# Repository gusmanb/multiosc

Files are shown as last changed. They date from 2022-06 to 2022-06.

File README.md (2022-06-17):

# MultiOsc
----
## Description
Two-channel 7Khz to 200Mhz clock/oscillator.

----
## Overview
MultiOsc is a very cheap two-channel clock generator which can be configured to generate frequencies from 8Khz to 200Mhz (180 to 200, depends on the SI5153 version) for less than 10€.

The device is based on the SI5351 clock generator, more concretely using the module sold in AliExpress (for less than 4€) which is very convenient as it already contains all the required external components to get it working immediately.

The device uses a STM32F103 module to control the clock generator and drive a 0.66" I2C screen.

## Schematic

The schematic is extremely simple, the three modules are connected through the I2C bus and five push buttons are used to control de menus, nothing more nothing else :)

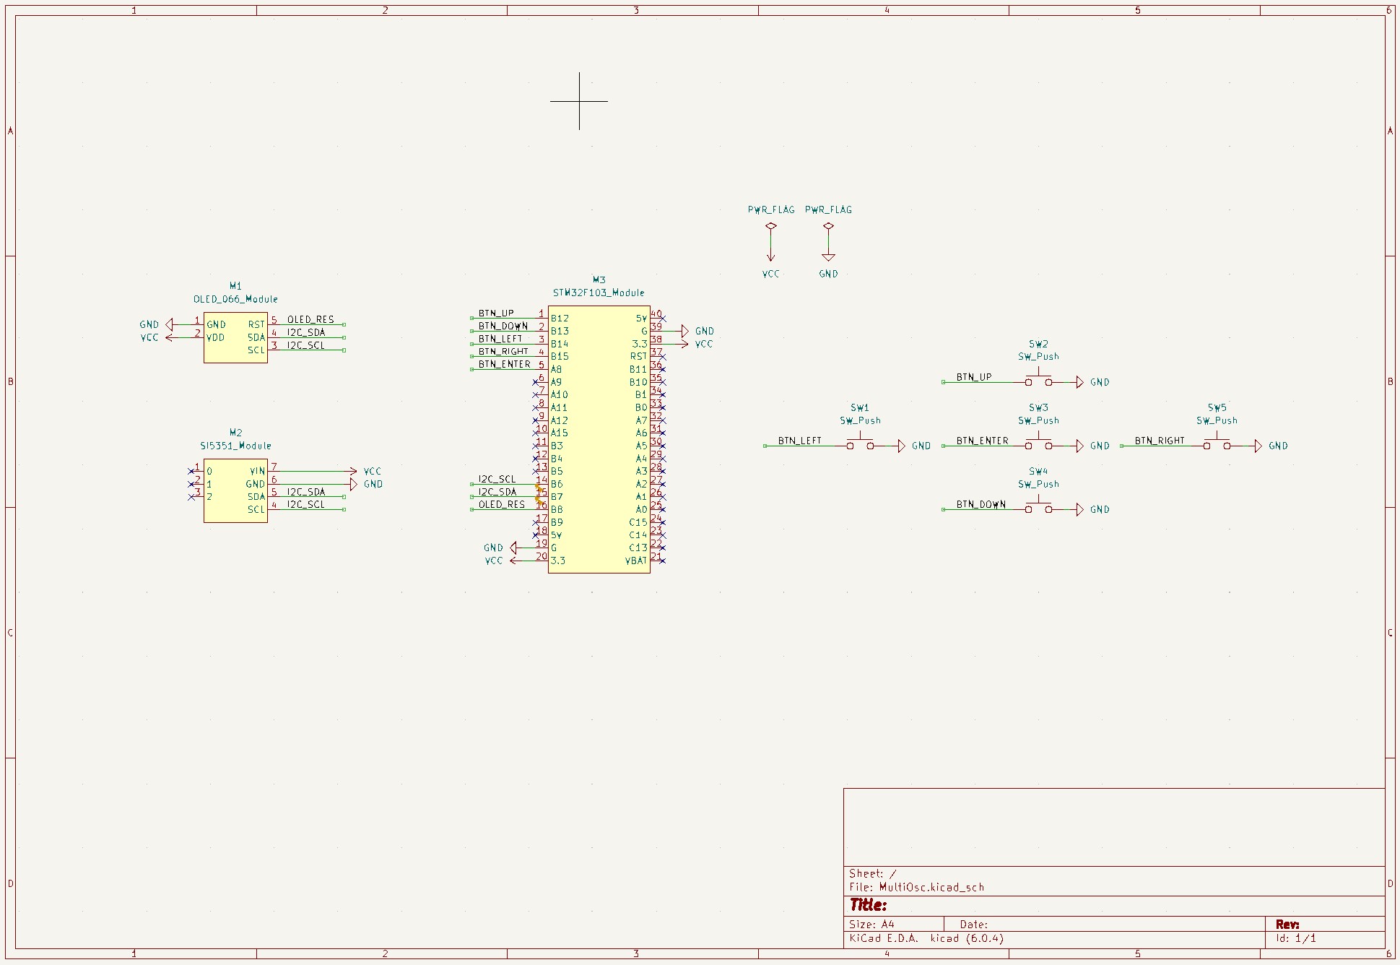
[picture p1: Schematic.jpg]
Schematic picture Schematic


## PCB

I also have included a very basic PCB to construct the device but it's not needed at all. I have assembled it using a protoboard and it works really well, but for anyone who wants to make it more robust the PCB is a good option.

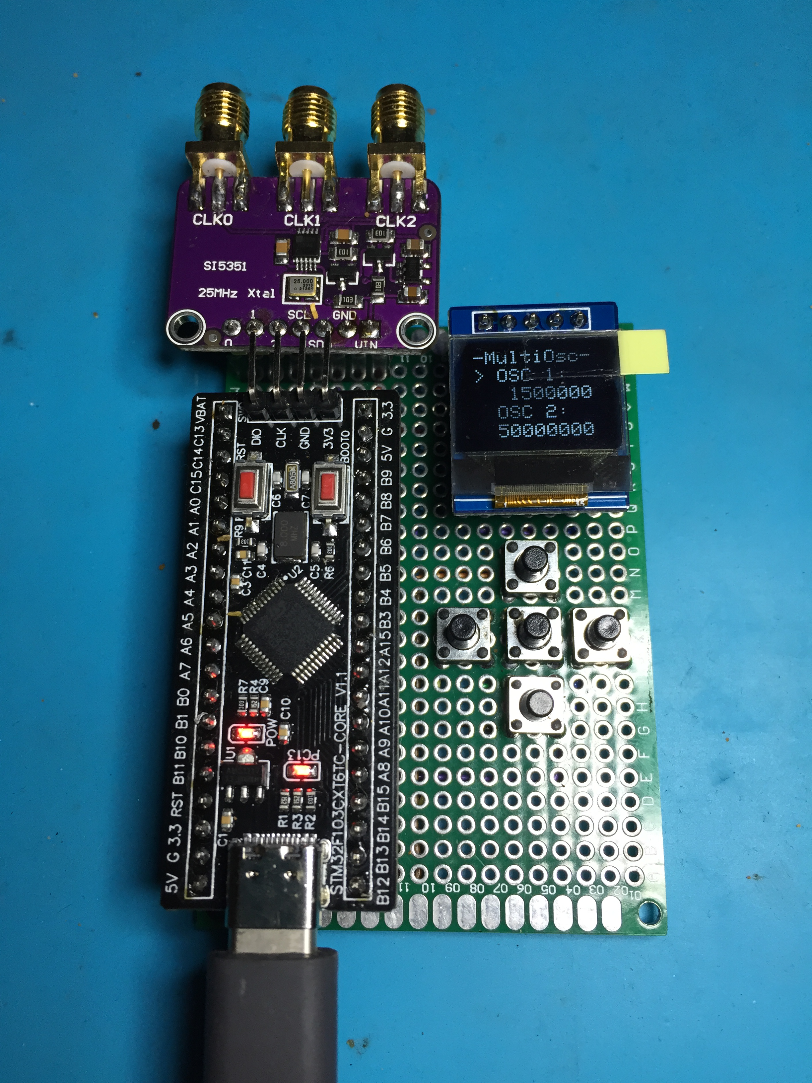
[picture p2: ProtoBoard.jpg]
ProtoBoard picture 1 ProtoBoard 1


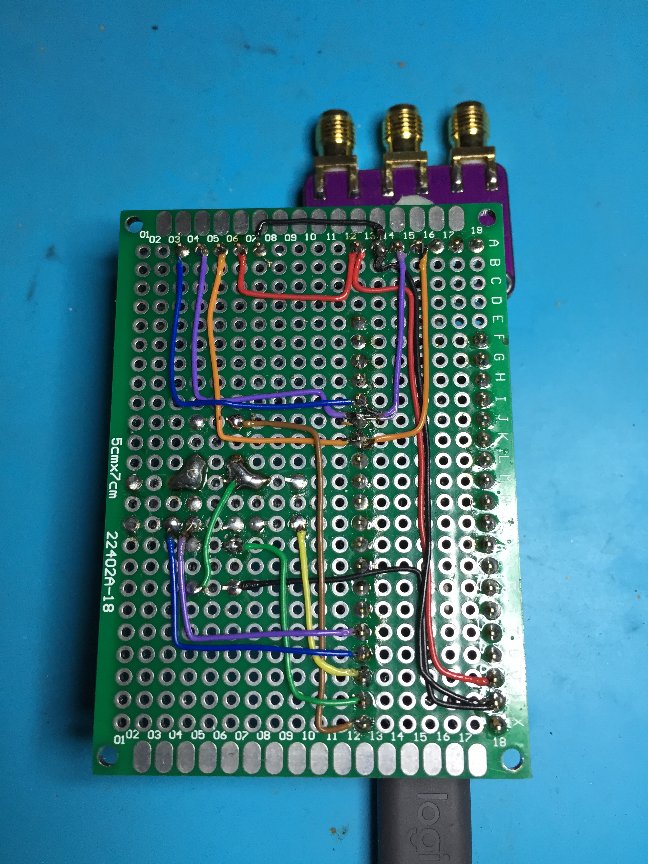
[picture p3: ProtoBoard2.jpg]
ProtoBoard picture 2 ProtoBoard 2


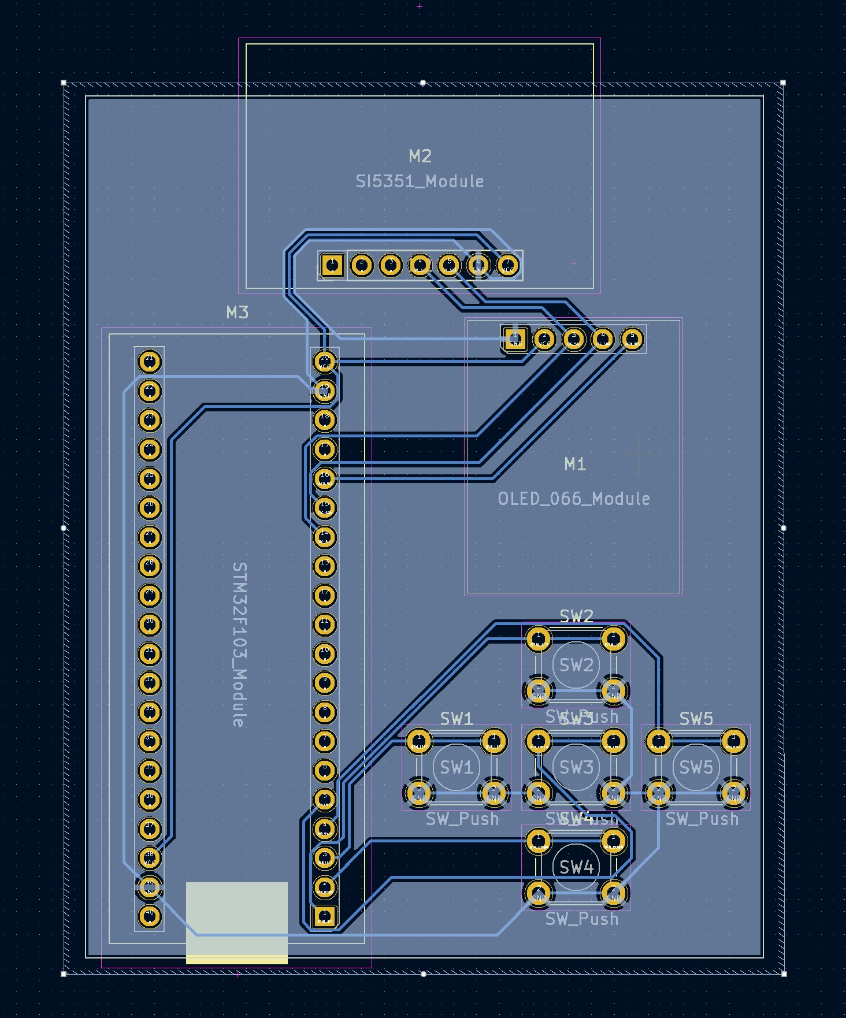
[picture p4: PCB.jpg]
PCB picture PCB


Both, schematic and PCB are included under the "PCB" folder, it's a KiCad 6.0 project and it includes all the custom footprints for the modules in case you want to reuse them.

## BOM

The bill of materials is very reduced:

* STM32F103 module:  https://es.aliexpress.com/item/1005002441720435.html
* 0.66" OLED screen: https://es.aliexpress.com/item/1005002760899272.html
* SI5351 module:     https://es.aliexpress.com/item/32915414654.html
* Push buttons (5):  https://es.aliexpress.com/item/1005004001434474.html

I am 99.99999% sure the STM module uses a clone uC, not an original STM device, but as far as I can tell the device works flawlessly.

## STM32F103 bootloader

I have seen a lot of people complaining about the F103 modules failing to run the bootloader, but this is all a missunderstanding on how the bootloader works for the F103.

If you check carefully the [AN2606](https://www.st.com/resource/en/application_note/cd00167594-stm32-microcontroller-system-memory-boot-mode-stmicroelectronics.pdf) it clarifies the problem and is really simple, the STM32F10XXX family only has UART bootloader and the modules connect the USB connector to the USB pins from these devices, there is no integrated serial-to-usb converter so the bootloader will not work connecting only the USB port, you also need a serial-to-usb converter and connect it to pins PA9 and PA10, with this the device will be accessible from STM32CubeProgrammer.

In any case I recommend to use a ST-LINK/V2 or similar (I have an original one and a clone, both work but the original one is less prone to cause errors and can be upgraded, so if you can, buy an original one), it works a lot faster and allows to debug the code in real time.

## Firmware

The firmware project is a STM32CubeIde project, currently I have used the 1.9.0 version and it uses the standard drivers and two heavily modified libraries.

The first library is the SSD1306 library by afiskon and you can find the original here: https://github.com/afiskon/stm32-ssd1306
The second library is the SI5351 library by MR-DOS and you can find the original here: https://github.com/MR-DOS/Si5351-lib

As you can imagine the firmware itself is very simple, it creates a menu where you can change the two output frequencies and that's all, nothing else is needed, and as it relies on the two aforementioned libraries controlling the screen and the SI module is a breeze.

Beware that I found there is a problem with CubeMX, if you open the CubeMX file to reconfigure the HAL drivers, pinout or whatever the CubeMX does break the I2C configuration, for the F103 device it does not allow to configure the port speed and without the configuration the I2C bus does not work. If you need to reconfigure the hardware, after re-generating the files you will need to modify the file "stm32f1xx_hal_msp.c" and add to the I2C initialization, before the "HAL_GPIO_Init" call, this: 

	GPIO_InitStruct.Speed = GPIO_SPEED_FREQ_HIGH;

---

Have fun!

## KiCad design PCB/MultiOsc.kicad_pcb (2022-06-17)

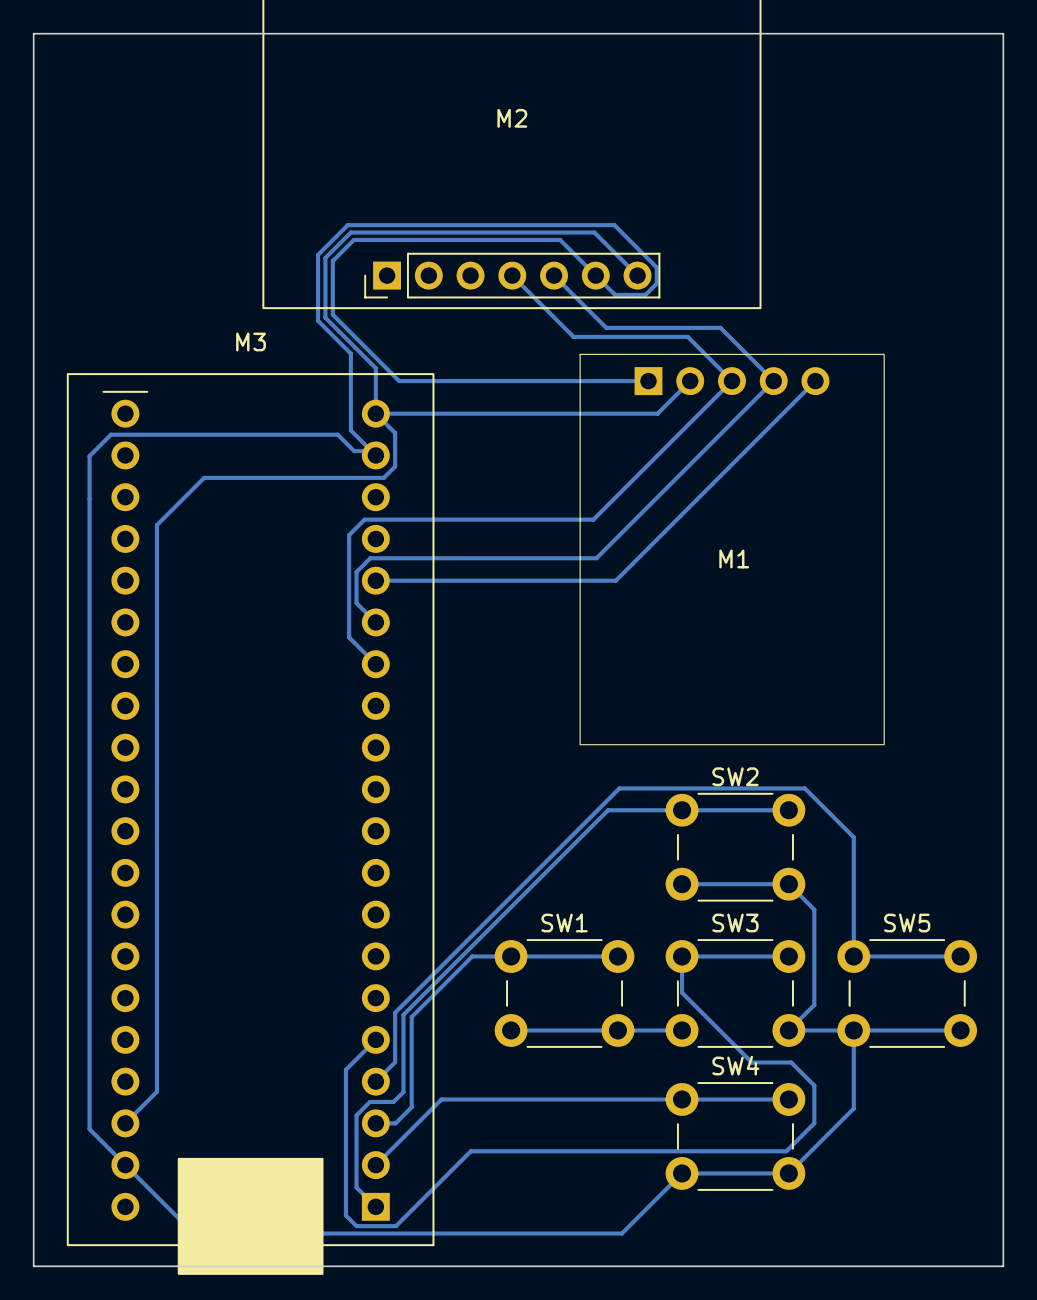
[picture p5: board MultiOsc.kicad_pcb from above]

Board: 2 copper layers, 59.0 x 75.0 mm, 8 parts (0 on the bottom side), 10 nets.

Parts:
M1: OLED_066_Module
M2: SI5351_Module
M3: STM32F103_Module
SW1, SW2, SW3, SW4, SW5: SW_Push; SW_PUSH_6mm_H7.3mm

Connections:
/BTN_DOWN: M3.2 (B13), SW4.1
/BTN_ENTER: M3.5 (A8), SW3.1
/BTN_LEFT: M3.3 (B14), SW1.1
/BTN_RIGHT: M3.4 (B15), SW5.1
/BTN_UP: M3.1 (B12), SW2.1
/I2C_SCL: M1.3 (SCL), M2.4 (SCL), M3.14 (B6)
/I2C_SDA: M1.4 (SDA), M2.5 (SDA), M3.15 (B7)
/OLED_RES: M1.5 (RST), M3.16 (B8)
GND: M1.1 (GND), M2.6 (GND), M3.19 (G), M3.39 (G), SW1.2, SW2.2, SW3.2, SW4.2, SW5.2
VCC: M1.2 (VDD), M2.7 (VIN), M3.20 (3.3), M3.38 (3.3)

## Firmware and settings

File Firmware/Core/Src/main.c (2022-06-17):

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
/* Includes ------------------------------------------------------------------*/
#include "main.h"

/* USER CODE BEGIN Includes */
#include "string.h"
#include "stdio.h"
#include "stdlib.h"
/* USER CODE END Includes */

/* USER CODE BEGIN PD */
#define XTAL_FREQ 25000000
/* USER CODE END PD */

 I2C_HandleTypeDef hi2c1;

/* USER CODE BEGIN PV */

Si5351_ConfigTypeDef si1;
uint32_t channel0Freq;
uint32_t channel1Freq;
uint8_t selectedChannel;
uint8_t currentChar;
uint8_t currentMenu;

char textBuffer[16];
char editBuffer[16];

/* USER CODE END PV */

void SystemClock_Config(void);
static void MX_GPIO_Init(void);
static void MX_I2C1_Init(void);
/* USER CODE BEGIN PFP */
static void MX_SI_Init(void);
static void MX_SCR_Init(void);
/* USER CODE END PFP */

/* USER CODE BEGIN 0 */

void SetFrequency(uint8_t channel, uint32_t desiredFrequency)
{

	uint32_t pllFreq;
	uint32_t l;
	float f;
	uint8_t mult;
	uint32_t num;
	uint32_t denom;
	uint32_t divider;
	Si5351_CLKRDivTypeDef rDivider = CLK_R_Div1;

	if(desiredFrequency == 0)
	{
		si1.CLK[channel].CLK_Enable = OFF;
		Si5351_Init(&si1);
		if(channel == 0)
			channel0Freq = 0;
		else
			channel1Freq = 0;

		return;
	}

	if(desiredFrequency < 1000000)
	{
		rDivider = CLK_R_Div64;
		divider = 900000000 / (desiredFrequency * 64);

		if (divider % 2)
			divider--;

		pllFreq = divider * desiredFrequency * 64;
	}
	else
	{
		divider = 900000000 / desiredFrequency;

		if (divider % 2)
			divider--;

		pllFreq = divider * desiredFrequency;
	}

	mult = pllFreq / XTAL_FREQ;
	l = pllFreq % XTAL_FREQ;

	if(l == 0)
	{
		num = 0;
		denom = 1;
	}
	else
	{
		f = l;


		f /= XTAL_FREQ;
		f *= 1048575;
		num = f;
		denom = 1048575;
	}

	float finalFreq = (25000000 * (float)(mult + (float)num / (float)denom)) / (divider);

	if(rDivider != CLK_R_Div1)
		finalFreq /= 64;

	si1.PLL[channel].PLL_Multiplier_Integer = mult; //800Mhz
	si1.PLL[channel].PLL_Multiplier_Numerator = num;
	si1.PLL[channel].PLL_Multiplier_Denominator = denom;
	si1.MS[channel].MS_Divider_Integer = divider;
	si1.CLK[channel].CLK_R_Div = rDivider;
	si1.CLK[channel].CLK_Enable = ON;

	Si5351_Init(&si1);
	Si5351_PLLReset(&si1, channel);

	if(channel == 0)
		channel0Freq = finalFreq;
	else
		channel1Freq = finalFreq;
}

void SelectOsc(uint8_t oscChannel)
{

	selectedChannel = oscChannel;
	if(oscChannel == 0)
	{
		ssd1306_SetCursor(0, 10);
		ssd1306_WriteString(">", Font_6x8, White);
		ssd1306_SetCursor(0, 30);
		ssd1306_WriteString(" ", Font_6x8, White);
	}
	else
	{
		ssd1306_SetCursor(0, 10);
		ssd1306_WriteString(" ", Font_6x8, White);
		ssd1306_SetCursor(0, 30);
		ssd1306_WriteString(">", Font_6x8, White);
	}

	ssd1306_UpdateScreen();
}

void ShowCurrentOscConfig()
{
	size_t freqLen;

	ssd1306_Fill(Black);

	ssd1306_SetCursor(0, 0);
	ssd1306_WriteString("-MultiOsc-", Font_6x8, White);

	ssd1306_SetCursor(0, 10);
	ssd1306_WriteString("  OSC 1:", Font_6x8, White);

	memset(textBuffer, 0, 16);
	sprintf(textBuffer, "%lu", channel0Freq);
	freqLen = strlen(textBuffer);

	ssd1306_SetCursor((10 - freqLen) * 6, 20);
	ssd1306_WriteString(textBuffer, Font_6x8, White);

	ssd1306_SetCursor(0, 30);
	ssd1306_WriteString("  OSC 2:", Font_6x8, White);

	memset(textBuffer, 0, 16);
	sprintf(textBuffer, "%lu", channel1Freq);
	freqLen = strlen(textBuffer);

	ssd1306_SetCursor((10 - freqLen) * 6, 40);
	ssd1306_WriteString(textBuffer, Font_6x8, White);

	SelectOsc(0);
}

uint8_t DebounceButton(GPIO_TypeDef* Port, uint16_t Pin)
{
	if(!HAL_GPIO_ReadPin(Port, Pin))
	{
		while(!HAL_GPIO_ReadPin(Port, Pin))
			HAL_Delay(1);

		HAL_Delay(50);

		return 1;
	}

	return 0;
}

void IncrementChar()
{
	uint8_t charIndex = 8 - currentChar;

	editBuffer[charIndex]++;

	if(editBuffer[charIndex] > 57)
		editBuffer[charIndex] = 48;

	ssd1306_SetCursor(6, 16);
	ssd1306_WriteString(editBuffer, Font_6x8, White);

	ssd1306_UpdateScreen();
}

void DecrementChar()
{
	uint8_t charIndex = 8 - currentChar;

	editBuffer[charIndex]--;

	if(editBuffer[charIndex] < 48)
		editBuffer[charIndex] = 57;

	ssd1306_SetCursor(6, 16);
	ssd1306_WriteString(editBuffer, Font_6x8, White);

	ssd1306_UpdateScreen();
}

void SelectChar(uint8_t charNumber)
{
	currentChar = charNumber;

	memset(textBuffer, ' ', 10);
	textBuffer[10] = 0;
	textBuffer[9 - charNumber] = '^';

	ssd1306_SetCursor(0, 24);
	ssd1306_WriteString(textBuffer, Font_6x8, White);

	ssd1306_UpdateScreen();
}

void ShowEditOscConfig()
{

	size_t freqLen;
	uint32_t currentFreq = selectedChannel? channel1Freq : channel0Freq;

	if(currentFreq == 0)
	{
		memset(editBuffer, 48, 10);
		editBuffer[9] = 0;
	}
	else
	{
		sprintf(editBuffer, "%lu", currentFreq);
		freqLen = strlen(editBuffer);
		memset(editBuffer, 48, 9);
		sprintf(&editBuffer[9 - freqLen], "%lu", currentFreq);
	}

	ssd1306_Fill(Black);
	ssd1306_SetCursor(0, 0);

	if(selectedChannel == 0)
		ssd1306_WriteString("SET OSC 1:", Font_6x8, White);
	else
		ssd1306_WriteString("SET OSC 2:", Font_6x8, White);

	ssd1306_SetCursor(6, 16);
	ssd1306_WriteString(editBuffer, Font_6x8, White);

	SelectChar(0);
}

/* USER CODE END 0 */

/**
  * @brief  The application entry point.
  * @retval int
  */
int main(void)
{
  /* MCU Configuration--------------------------------------------------------*/

  /* Reset of all peripherals, Initializes the Flash interface and the Systick. */
  HAL_Init();

  /* Configure the system clock */
  SystemClock_Config();

  /* Initialize all configured peripherals */
  MX_GPIO_Init();
  MX_I2C1_Init();
  /* USER CODE BEGIN 2 */

  MX_SI_Init();
  MX_SCR_Init();
  /* USER CODE END 2 */

  /* Infinite loop */
  /* USER CODE BEGIN WHILE */
  while (1)
  {
    /* USER CODE END WHILE */

    /* USER CODE BEGIN 3 */

	  HAL_GPIO_TogglePin(LED_GPIO_Port, LED_Pin);


	  if(currentMenu == 0)
	  {
		  if(DebounceButton(BTN_UP_GPIO_Port, BTN_UP_Pin) || DebounceButton(BTN_DOWN_GPIO_Port, BTN_DOWN_Pin))
		  {
			  if(selectedChannel == 0)
				  SelectOsc(1);
			  else
				  SelectOsc(0);
		  }
		  else if(DebounceButton(BTN_ENTER_GPIO_Port, BTN_ENTER_Pin))
		  {
			  currentMenu = 1;
			  ShowEditOscConfig();
		  }
	  }
	  else
	  {
		  if(DebounceButton(BTN_LEFT_GPIO_Port, BTN_LEFT_Pin))
		  {
			  currentChar++;
			  if(currentChar > 8)
				  currentChar = 0;

			  SelectChar(currentChar);
		  }
		  else if(DebounceButton(BTN_RIGHT_GPIO_Port, BTN_RIGHT_Pin))
		  {
			  currentChar--;
			  if(currentChar > 8)
				  currentChar = 8;

			  SelectChar(currentChar);
		  }
		  else if(DebounceButton(BTN_UP_GPIO_Port, BTN_UP_Pin))
		  {
			  IncrementChar();
		  }
		  else if (DebounceButton(BTN_DOWN_GPIO_Port, BTN_DOWN_Pin))
		  {
			  DecrementChar();
		  }
		  else if(DebounceButton(BTN_ENTER_GPIO_Port, BTN_ENTER_Pin))
		  {
			  uint32_t newFreq = (unsigned)atol(editBuffer);

			  if(newFreq < 7000)
				  newFreq = 0;

			  SetFrequency(selectedChannel, newFreq);
			  currentMenu = 0;
			  ShowCurrentOscConfig();
		  }
	  }

  }
  /* USER CODE END 3 */
}

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
/* USER CODE BEGIN 4 */

static void MX_SI_Init(void)
{
	Si5351_StructInit(&si1, &hi2c1);
	si1.OSC.OSC_XTAL_Load = XTAL_Load_10_pF;

	si1.PLL[0].PLL_Clock_Source = PLL_Clock_Source_XTAL;
	si1.PLL[0].PLL_Multiplier_Integer = 32; //800Mhz
	si1.MS[0].MS_Clock_Source = MS_Clock_Source_PLLA;
	si1.MS[0].MS_Divider_Integer = 80; //10Mhz
	si1.CLK[0].CLK_R_Div = CLK_R_Div1;
	si1.CLK[0].CLK_Enable = OFF;

	si1.PLL[1].PLL_Clock_Source = PLL_Clock_Source_XTAL;
	si1.PLL[1].PLL_Multiplier_Integer = 32; //800Mhz
	si1.MS[1].MS_Clock_Source = MS_Clock_Source_PLLB;
	si1.MS[1].MS_Divider_Integer = 50; //10Mhz
	si1.CLK[1].CLK_R_Div = CLK_R_Div16; //1Mhz
	si1.CLK[1].CLK_Enable = OFF;

	si1.CLK[2].CLK_Enable = OFF;

	Si5351_Init(&si1);

	channel0Freq = 0;
	channel1Freq = 0;
}

static void MX_SCR_Init(void)
{
	ssd1306_Init();
	ShowCurrentOscConfig();
}

/* USER CODE END 4 */
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


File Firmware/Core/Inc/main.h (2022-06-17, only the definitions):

#define LED_Pin GPIO_PIN_13
#define LED_GPIO_Port GPIOC
#define BTN_UP_Pin GPIO_PIN_12
#define BTN_UP_GPIO_Port GPIOB
#define BTN_DOWN_Pin GPIO_PIN_13
#define BTN_DOWN_GPIO_Port GPIOB
#define BTN_LEFT_Pin GPIO_PIN_14
#define BTN_LEFT_GPIO_Port GPIOB
#define BTN_RIGHT_Pin GPIO_PIN_15
#define BTN_RIGHT_GPIO_Port GPIOB
#define BTN_ENTER_Pin GPIO_PIN_8
#define BTN_ENTER_GPIO_Port GPIOA
#define OLED_RESET_PIN_Pin GPIO_PIN_8
#define OLED_RESET_PIN_GPIO_Port GPIOB

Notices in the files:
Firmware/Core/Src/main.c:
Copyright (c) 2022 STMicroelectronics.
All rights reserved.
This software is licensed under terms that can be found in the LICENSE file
